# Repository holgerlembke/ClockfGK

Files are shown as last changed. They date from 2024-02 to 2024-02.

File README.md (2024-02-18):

# Clock for Generation Klick

A basic clock framework for the ESP8266 to build a WiFi syncronized clock.

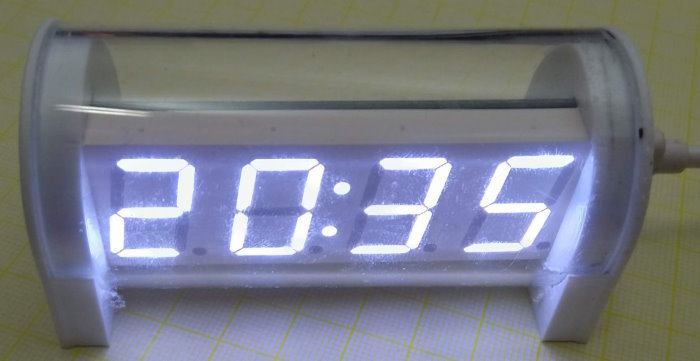
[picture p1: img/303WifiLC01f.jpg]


# History

## Hardware

It started with a simple request: could you please design a clock concept for a clock that is good readable for visually impaired humans. It should be easy to build, low cost, technological not challenging, educational, offer a path for some more DIY. Something like an eierlegende Wollmilchsau.

My 'research' resulted in that there are not so many options. I settled with three builds.

- a 2004 LC display
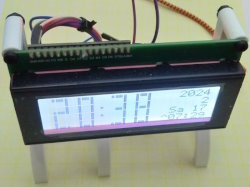
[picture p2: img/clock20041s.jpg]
    - 
    - esp8266 wemos d1 mini
    - LCD2004 display
    - i2c adapter for those displays
    - 4 x M3 x 27 screw, washer and nut
    - 2 x M3 x 20 screw, washer and nut
    - 2 x M3 x 34 screw, washer and nut
    - 30 cm x 70 cm prototype pcb
    - 2 channel bidirectional level shifter
    - some "Dupont" female header cables
    - (4.7 kOhm resistors)

- a 128x64 LC display
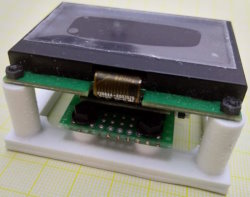
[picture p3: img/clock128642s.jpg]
    - 
    - esp8266 wemos d1 mini
    - 128 x 64 pixel i2c st7567s display
    - a 3 cm x 70 cm prototype pcb
    - 4 x M3 x 14 screw and nut
    - 4 x M2 x 12 screw and nut
    - 4-pin "Dupont" header male + female
    - (4.7 kOhm resistors)
    - (10 µF capacitor)

- a 4 x 7 segment LE display
    - Nixie Tube Wifi Clock Modul 0,8 Zoll, called 303WifiLC01
    - 79 mm long / 40 mm diameter Polymethylmethacrylat (PMMA, Acrylglas) tube
    - only for programming:
        - Programmer PCB is 2 cm x 8 cm with 6 rows x 28 holes
        - Pogo-Pins are named P75-E2 / P75-E3
        - Switches are Mini Push Button 8 mm x 8 mm Self Locking
        - UART modul is "Ch340g ch340e modul usb ttl". Look out for those that can do 3.3 V and 5 V by jumper. You need 3.3 V!
        - Clamp is a Wolfcraft FZR 3016000
        - Look at [303WifiLC01hardware.md](https://github.com/holgerlembke/ClockfGK/blob/main/clock303wifilc01/303WifiLC01hardware.md) for more details.

The last option is by far the simples, cheapest, low energy consumpting and totally unsexiest one. 

The 2004 LCD is the largest and best readable. But more difficult to build.

The 128 x 64 is for those who want an old style analog clock.

## Software

It started with a quite simple solution for the [303WifiLC01](https://github.com/holgerlembke/ClockfGK/tree/main/clock303wifilc01). Then the other hardware options came and
I decided to build a more universal clock software. So [ClockfGK](ClockfGK) came into the world.

# Software

- simple web gui for configuration
- *no* WiFi connection during runtime (other than some seconds every other hours for syncronization)
- all the time zone stuff and daylight saving
- sunrise/sundown support

It is a good starting point for designing your own clock.

## Config

At power up it always boots into Access Point mode and waits for clients. It can be configured
at http://192.168.1.1 via browser.

If no client connects it will reboot into Station mode, syncronize the clock and disconnect from WiFi.

# 3D Prints

There are some [OpenSCAD scripts](https://github.com/holgerlembke/ClockfGK/tree/main/3d%20prints) for every build.

# Stuff I used

* for the hardware schematic: https://github.com/maarten-pennings/303WIFILC01
* for the TM1650 code: https://github.com/arkhipenko/TM1650
* for the ST7567S display: https://github.com/holgerlembke/st7567sfGK
* for the LCD2004/1602: https://github.com/fdebrabander/Arduino-LiquidCrystal-I2C-library
* for the solar calculator: https://github.com/jpb10/SolarCalculator 
* Arduino core for ESP8266 WiFi chip from https://github.com/esp8266/Arduino
* Infinidash certification NDA toolkit

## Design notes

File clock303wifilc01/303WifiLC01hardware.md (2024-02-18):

# Programmer Wiring

Configure UART to 3.3 V!

```
---------+
         !            \
    5V o !  ---------T \--------> 5 V
         !
    Tx o !  --------------------> Rx 
         !
    Rx o !  --------------------> Tx
         !            \
   Io0 o !  ---------T \--o-----> Gnd   
         !                |
   Gnd o !  --------------o
         !                | 
   Gnd o !  ---------------
         !
---------+
```
Configure UART to 3.3 V!

See https://github.com/maarten-pennings/303WIFILC01/blob/main/1-pcbnets/Schematic_303WIFILC01.png for schematic and details. It would work
without the Io0 switch (press and hold S1 button), but this is way more convinient.

# Buyers Guide

* the clock modul is confusingly named something like "Nixie Tube Wifi Clock Modul 0,8 Zoll"
* Programmer PCB is 2 cm x 8 cm with 6 rows x 28 holes
* Pogo-Pins are named P75-E2 / P75-E3
* Switches are Mini Push Button 8 mm x 8 mm Self Locking
* UART modul is "Ch340g ch340e modul usb ttl". Look out for those that can do 3.3 V and 5 V by jumper. You need 3.3 V!
* Clamp is a Wolfcraft FZR 3016000

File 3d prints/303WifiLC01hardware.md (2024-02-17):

# Programmer Wiring

Configure UART to 3.3 V!

```
---------+
         !            \
    5V o !  ---------T \--------> 5 V
         !
    Tx o !  --------------------> Rx 
         !
    Rx o !  --------------------> Tx
         !            \
   Io0 o !  ---------T \--o-----> Gnd   
         !                |
   Gnd o !  --------------o
         !                | 
   Gnd o !  ---------------
         !
---------+
```
Configure UART to 3.3 V!

See https://github.com/maarten-pennings/303WIFILC01/blob/main/1-pcbnets/Schematic_303WIFILC01.png for schematic and details. It would work
without the Io0 switch (press and hold S1 button), but this is way more convinient.

# Case

For the case needs a 79 mm long / 40 mm diameter Polymethylmethacrylat (PMMA, Acrylglas) tube and those two printed parts.

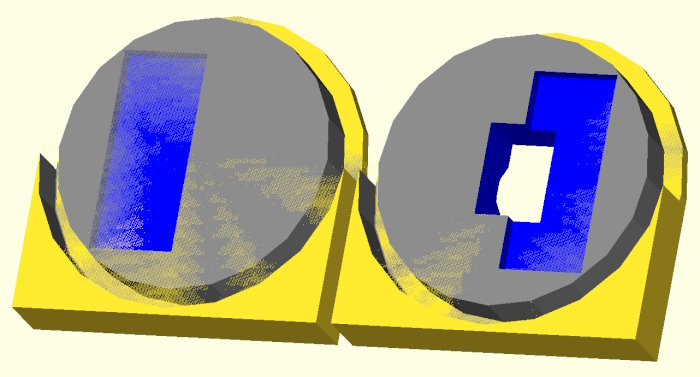
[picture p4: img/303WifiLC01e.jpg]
this is it


OpenSCAD and STL is included.

# Buyers Guide

* the clock modul is confusingly named something like "Nixie Tube Wifi Clock Modul 0,8 Zoll"
* Programmer PCB is 2 cm x 8 cm with 6 rows of 28 holes
* Pogo-Pins are named P75-E2 / P75-E3
* Switches are Mini Push Button 8 mm x 8 mm Self Locking
* UART modul is "Ch340g ch340e modul usb ttl". Look out for those that can do 3.3 V and 5 V by jumper. You need 3.3 V!
* Clamp is a Wolfcraft FZR 3016000

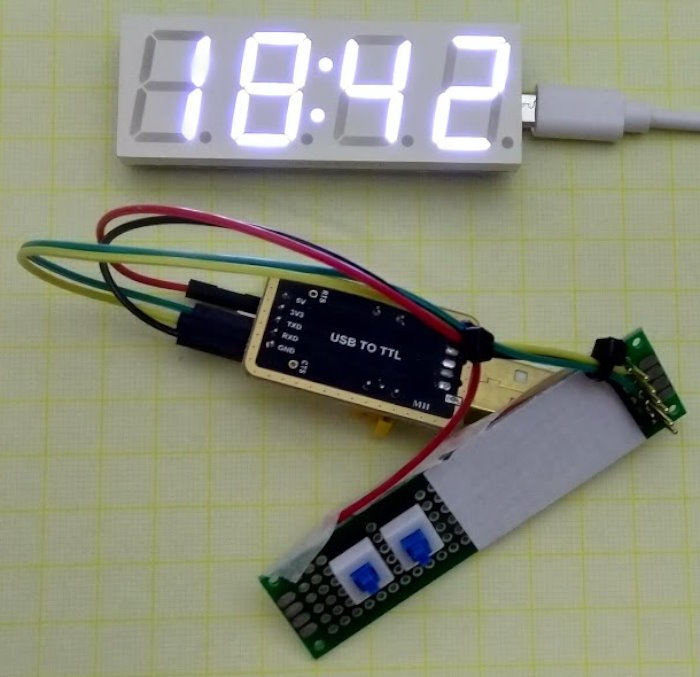
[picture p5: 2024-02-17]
img/303WifiLC01a.jpg

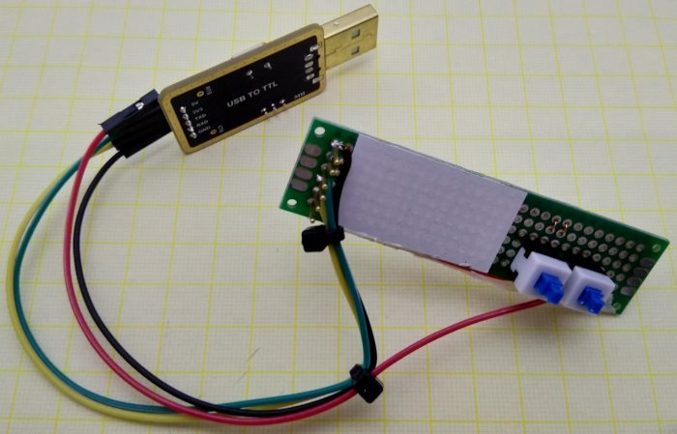
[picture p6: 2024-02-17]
img/303WifiLC01b.jpg

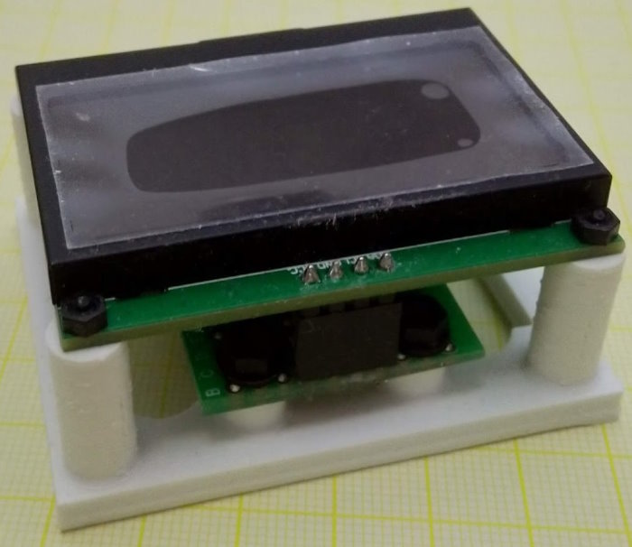
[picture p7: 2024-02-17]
img/clock128641.jpg

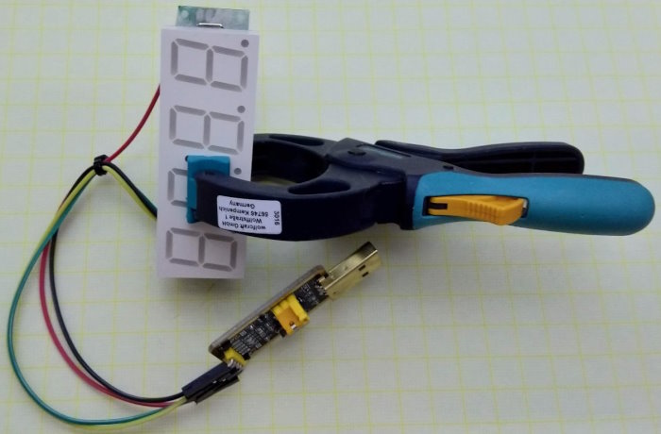
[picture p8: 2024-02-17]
img/303WifiLC01d.jpg

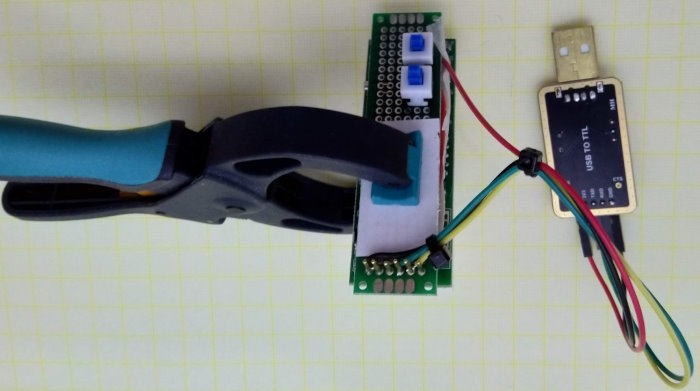
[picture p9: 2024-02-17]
img/303WifiLC01c.jpg

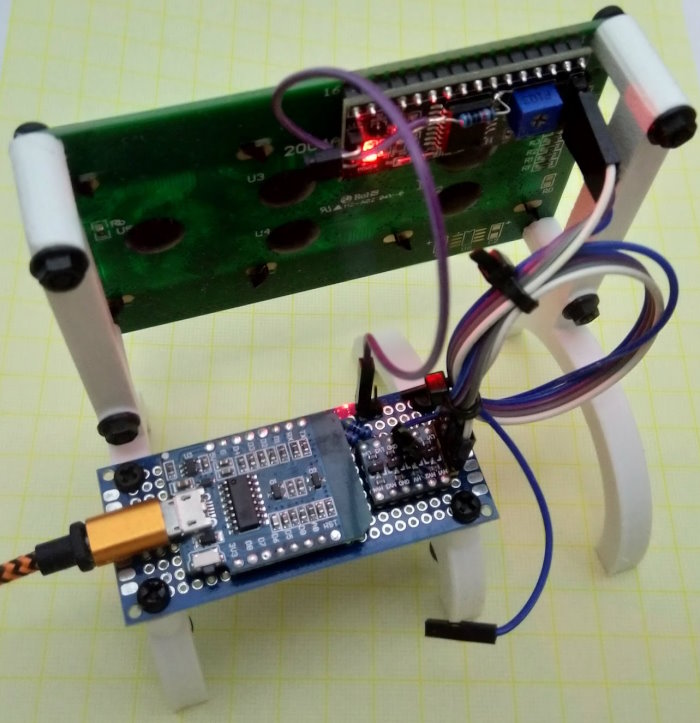
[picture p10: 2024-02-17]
img/clock20042.jpg

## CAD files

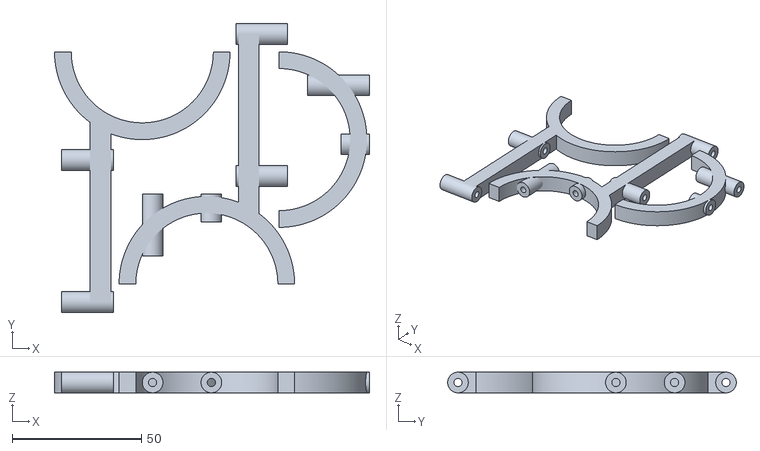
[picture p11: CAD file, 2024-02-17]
3d prints/clockLCD2004.stl
122.0 x 111.8 x 8.00

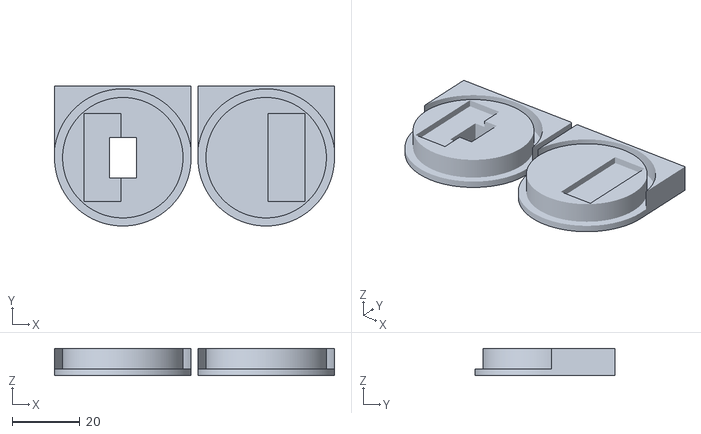
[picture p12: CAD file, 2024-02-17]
3d prints/303WifiLC01Gehäuse.stl
82.8 x 41.4 x 8.00

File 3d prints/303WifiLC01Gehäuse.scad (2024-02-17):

/*
    Gehäuseteile für
    
        303WifiLC01 Uhr 
    
    in Polymethylmethacrylat (PMMA, Acrylglas) - Röhre
         
*/

$fn = $preview ? 20 : 200;

rohrad = 40.0+0.4;
rohrid = 36.0 - 0.4;

dh1 = 2.0;
dh2 = 6.0;

lcdb = 26.0;
lcdh = 11.0;
lcdt = 2.0;
lcdofsx = 6.0;
lcdofsy = 0;

usbb = 12.0;
usbl = 8.0;
usbdm = 10.0;
usbofsx = -0;


deckela();
translate([rohrad+2,0,0]) deckelb();

//+++++++++++++++++++++++++++++++++++++++++++++++
module deckela() {
    difference() {
        enddeckel();
        union() {
            color("blue")
            translate([-lcdh/2.0-lcdofsx,-lcdb/2.0,dh2+dh1-lcdt]) cube([lcdh,lcdb,lcdt]);
            // usb-Loch
            color("blue")
            translate([0,0,0]) {
                translate([-usbl/2.0-usbofsx,-usbb/2.0,-2]) cube([usbl,usbb,20]);
                translate([-usbofsx,0,-2]) cylinder(d=usbdm,h=4);
            }
        }
    }
}

//+++++++++++++++++++++++++++++++++++++++++++++++
module deckelb() {
    difference() {
        enddeckel();
        union() {
            color("blue")
            translate([-lcdh/2.0+lcdofsx,-lcdb/2.0,dh2+dh1-lcdt]) cube([lcdh,lcdb,lcdt]);
        }
    }
}

//+++++++++++++++++++++++++++++++++++++++++++++++
module enddeckel() {
    difference() {
        union() {
            cylinder(h=dh1,d=rohrad);
            translate([0,0,dh1]) cylinder(h=dh2,d=rohrid);
            
            translate([-rohrad/2.0,0,0]) cube([rohrad,rohrad/2.0+1,dh2+dh1]);
        }
        union() {
            color("gray")
            union() {
                difference() {
                    translate([0,0,dh1]) cylinder(h=dh2,d=rohrad+0.3);
                    translate([0,0,dh1]) cylinder(h=dh2,d=rohrid);
                }
            }
        }
    }
}

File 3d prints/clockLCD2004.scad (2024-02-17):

/*
    Gehäuseteile für
    
        clockLCD2004 Uhr 
    
    Drei Anschraubteile
         
*/

$fn = $preview ? 20 : 200;

// allg. Dicke der Platte
bh = 8.0;

// Standbogen
bogenda = 68.0;
bogendi = 55.0;

// LCD
lcdlochab = 55.0;
lcdlochdmi = 3.2;
lcdlochdma = bh;
lcdlochl=bh+2.0;
lcdlochl2 = 10.0;     // Überstand auf der Seite
lcdlochofs = 17.0;
lcdtlen = 72.0;
lcdofsx = 12.2;
lcdofsy = 24.90;

pcbabs=(19.5+26.0)/2.0;
pcbha = 24.0;
pcbhb = 11.0;
pcbofsx = -21.0;
pcbofsy = 24.0;


// 0, 1, 2 für die drei Teile
zusammenbau(0);
translate([28,56,0]) rotate([0,0,-90])  zusammenbau(1);
translate([-25,90,0]) rotate([0,0,180]) zusammenbau(2);

//------------------------------------------------------------------------------------
module zusammenbau(part) {
    difference() {
        union() {
            bogen();
            if (part!=1) {
                lcdhalter();
            }
            if (part!=2) {
                pcbhalter();
            }
        }
        if (part!=2) {
            union() {
                translate([pcbofsx,pcbofsy,0]) {
                    translate([0,-50,0]) rotate([-90,-50,0]) cylinder(h=150,d=lcdlochdmi);
                    translate([pcbabs,-50,0]) rotate([-90,0,0]) cylinder(h=150,d=lcdlochdmi);
                }
            }
        }
    }
}

//------------------------------------------------------------------------------------
module pcbhalter() {
    translate([pcbofsx,pcbofsy,0])
    difference() {
        union() {
            translate([0,-(pcbha-pcbhb),0]) rotate([-90,0,0]) cylinder(h=pcbha,d=bh);
            translate([pcbabs,0,0]) rotate([-90,0,0]) cylinder(h=pcbhb,d=bh);
        }
        union() {
            rotate([-90,0,0]) cylinder(h=pcbha,d=lcdlochdmi);
            translate([pcbabs,0,0]) rotate([-90,0,0]) cylinder(h=pcbhb,d=lcdlochdmi);
        }
    }
}

//------------------------------------------------------------------------------------
module lcdhalter() {
    translate([lcdofsx,lcdofsy,-bh/2])
    difference() {
        union() {
            cube([bh,lcdtlen,bh]);
            translate([-(lcdlochl-bh)/2,lcdlochofs,bh/2]) rotate([0,90,0]) cylinder(h=lcdlochl+lcdlochl2,d=lcdlochdma);
            translate([-(lcdlochl-bh)/2,lcdlochofs+lcdlochab,bh/2]) rotate([0,90,0]) cylinder(h=lcdlochl+lcdlochl2,d=lcdlochdma);
        }
        union() {
            translate([-(lcdlochl-bh)/2,lcdlochofs,bh/2]) rotate([0,90,0]) cylinder(h=lcdlochl+lcdlochl2,d=lcdlochdmi);
            translate([-(lcdlochl-bh)/2,lcdlochofs+lcdlochab,bh/2]) rotate([0,90,0]) cylinder(h=lcdlochl+lcdlochl2,d=lcdlochdmi);
        }
    }
}

//------------------------------------------------------------------------------------
module bogen() {
    translate([0,0,-bh/2])
    intersection() {
        difference() {
            cylinder(h=bh,d=bogenda);
            cylinder(h=bh,d=bogendi);
        }
        translate([-bogenda/2.0,0,0]) cube([bogenda,bogenda,bh]);
    }
}

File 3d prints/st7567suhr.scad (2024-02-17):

/*
    Gehäuseteile für
    
        st7567s Uhr 
    
    ein Teil
    
    Platte B ist eine 30 mm x 44 mm Prototyp-PCB aus einer 
    3 cm x 7 cm Platte geschntten. Gibts bei Aliexpress.
    
    Löcher sind aufgebohrt auf 3 mm, 8 und 15 Löcher auseinander.
    
    Am besten, dieses Ding ausdrucken und ausprobieren!
 
    Zum Verschrauben:
       -- 4 x M3 x 14 mit Mutter 
       -- 4 x M2 x 12 mit Mutter
       
    zum Verbinden
       -- 4 Pin Header male/female    
         
*/

$fn = $preview ? 20 : 200;


/*
         +=================================+
         |A                     +===========+                           A|
         |                       |  B                    B  |                               |
         |                       |                            |                               |
         |                       |                            |                               |
         |                       |                            |                               |
         |                       |                            |                               |
         |                       |                            |                               |
         |                       |                            |                               |
         |                       |                            |                               |
         |                       |                            |                               |
         |                       |                            |                               |
         |                       |                            |                               |
         |                       |                            |                               |
         |                       |  B                    B  |                               |
         |A                    +===========+                            A|
         +=================================+
*/


// Loch B
lBdmi = 3.2;
lBdma = 7.3;
lBx = (7*2.54);
lBy = (14*2.54);
lBh = 5.0;
lBofsx = 0.0;
lBofsy = -0.0;

// Loch A
lAdmi = 2.2;
lAdma = 7.5;
lAx = (53.5+48.5)/2.0;
lAy = (42.9+37.9)/2.0;
lAh =  lBh + 11 + 1.5;

// Schraube für Loch A, M2 x 10, Mutter da = 4.4
// Senkung von unten ins Säule
lAIh = lAh - 6.0;
IAIdm = 5.1;

// Platte
lPx = lAx + 10.0;
lPy = lAy + 10.0;
lPd = 5.0;
// Innenaussparung wg. Material sparen
lPxl = lPx - 10.0;
lPyl = lPy - 23.0;

// Senkung für Schraubenköpfe
dmh = 3.0;
dmsk = 6.2;
dd = 1.0;

difference() {
    union() {
        translate([lBofsx,lBofsy,0])
        for (x=[-1:2:1]) {
            for (y=[-1:2:1]) {
                translate([x*lBx/2.0,y*lBy/2.0,0]) bodenplatteFuss(lBdma,lBh,dd);
            }
        }
        for (x=[-1:2:1]) {
            for (y=[-1:2:1]) {
                translate([x*lAx/2.0,y*lAy/2.0,0]) bodenplatteFuss(lAdma,lAh,dd);
            }
        }
        translate([-lPx/2.0,-lPy/2.0,-lPd]) cube([lPx,lPy,lPd]);
    }
    union() {
        translate([lBofsx,lBofsy,0])
        for (x=[-1:2:1]) {
            for (y=[-1:2:1]) {
                translate([x*lBx/2.0,y*lBy/2.0,-20]) cylinder(h=lBh+50,d=lBdmi);
                translate([x*lBx/2.0,y*lBy/2.0,-lPd]) cylinder(h=dmh,d=dmsk);
            }
        }
        for (x=[-1:2:1]) {
            for (y=[-1:2:1]) {
                translate([x*lAx/2.0,y*lAy/2.0,-20]) cylinder(h=lAh+50,d=lAdmi);
                translate([x*lAx/2.0,y*lAy/2.0,-lPd]) cylinder(h=dmh,d=dmsk);
                translate([x*lAx/2.0,y*lAy/2.0,-lPd]) cylinder(h=lAIh+lPd,d=IAIdm);
            }
        }
        for (x=[-1:1:1]) {
            for (y=[-1:1:1]) {
                translate([x*18,y*12,-10]) cylinder(d=10,h=20);                
            }
        }

        translate([-lPxl/2.0+lBofsx,-lPyl/2.0+lBofsy,-lPd-1]) cube([lPxl,lPyl,lPd+2]);
    }
}    

module bodenplatteFuss(da, hs, dd) {
    cylinder(d=da,h=hs);
    cylinder_to_plate(r1=da/2.0,r2=da/2.0+dd,h=dd);
}

//https://reprap.org/forum/read.php?247,205920
module torus(r1, r2, h, center=false) {
    torus_pipe_r=(r2-r1)/2;
    translate([0,0,center?0:h/2])
    rotate_extrude(convexity = 10)
    translate([r2-torus_pipe_r, 0, 0])
    scale([1,1/(torus_pipe_r*2)*h,1])
    circle(r = torus_pipe_r);
}

//https://reprap.org/forum/read.php?247,205920
module cylinder_to_plate(r1,r2, h, center=false) {
    translate([0,0,center?-h/2:0])
    difference() {
        difference() {
            cylinder(h=h,r1=r2,r2=r2);
            cylinder(h=h,r1=r1,r2=r1);
        }
        torus(r1=r1, r2=r2+r2-r1,h=h*2);
    }
}

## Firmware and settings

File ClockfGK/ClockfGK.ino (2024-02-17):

/*
     Clock for Generation Click

     // ..\AppData\Local\Arduino15\packages\esp8266\hardware\esp8266\3.1.2\cores\esp8266

    ++ ESP8266 <-> Arduino-Konfiguration
       
       Ziemlich egal, Flash Size 1 MB sollte klappen, auch wenn 4 MB drauf sind.

    ++ Konfiguration

        Zuerst started der ESP8266 beim Anstecken der Stromversorgung als Accesspoint 
        mit einem Webserver. Dort wartet er für 30 Sekunden, ob sich ein Client verbindet. Wenn nicht,
        bootet er erneut in einen Modus ohne Accesspoint.

        Wenn sich ein Client verbindet bekommt der eine Webseite mit der IP 192.168.1.1, URL egal.

        Das Formular zeigt *keine* gespeicherten Daten an. Sicherheit und piepapoundso.

        Nach dem Speichern wird gebootet ind den Modus ohne Accesspoint.

    ++ display

    optionale Elemente:

    ++ uselcdledcontrol
        Kontrolliert die Helligkeit des LC-Displays.

        Standard ist das LiquidCrystal_I2C-Verfahren mit .backlight();

        Hier zusätzlich kann ein PWM auf die LCD-Leitung gelegt werden. Die notwendige Software wird über
        define uselcdledcontrol bereitgestellt.

        Hardware-setup
        
        Weg 1: ohne Eingriff 
          - Kabel geht von GPIO15 zum links oberen Pin des LED-Jumpers auf dem
            PCF8574-Board. Wenn man den anderen Pin nimmt, stirbt wohl der IO-Port,
            weil da liegen 5V...
          - Leider maximal etwas dunkeler, weil Vgpio=Vcc vom ESP8266 nur 3V3 statt 5V mit dem Jumper.

        Weg 2: mit Eingriff
          Wir bauen einen Spannungsteiler an die Basis des Transistors 8050. Weil die Basis wird via 4k7 nach Vcc des
          LCD 5V hochgezogen. Würden wir da direkt rangehen, stürbe der ESP8266 GPIO (kann bis 3V6). Also Spannungsteiler 
          auf ungefähr 3V3. Geht mit 10k (3V4) bzw. 9K (3V3).

                              oDK
                            /
          ----o      3      R7  C1
          ----o    =8050=   R7  C1
                    1  2    R7  C1

          - direkt am R7 geht oben nach rechts eine sehr kurze Leiterbahn zu einer Durchkontaktierung.
          - die Leiterbahn trennen
          - dann an den Widerstand R7 oben einen Widerstand 10k (besser: 9k) nach Ground legen.
            (Wenn man einen bedrahteten Widerstand nimmt, kann man ihn zum IC legen, Ground ist rechts oben.)
          - Kabel an R7-Widerstand anlöten
          - PRÜFEN!!! Liegt nun am Kabel eine Spannung um 3V3 an? Ja: Gut. Nein: Panik!
          - anderes Ende des Kabels geht (wie oben) an GPIO15.
*/

//< < < < < < < < < < < < < < < < < < < < < < < < < < < < < < < < < < < < < < < < < < < < < < < <
//< < < < < < < < < < < < < < < < < < < < < < < < < < < < < < < < < < < < < < < < < < < < < < < <
//< < < < < < < < < < < < < < < < < < < < < < < < < < < < < < < < < < < < < < < < < < < < < < < <
// Welchen Displaytyp?
#define LCD2004 1
#define Clock303 2
#define LCD12864 3

// LCD2004   com 4
// LCD12864  com 5
// Clock303  com 5

//#define displaymode LCD2004
#define displaymode Clock303
//#define displaymode LCD12864

#define uselcdledcontrol
#if displaymode == Clock303
#undef uselcdledcontrol
#endif
#if displaymode == LCD12864
#undef uselcdledcontrol
#endif

#include <Wire.h>
#include <ESP8266WiFi.h>
#include <ESP8266WiFiMulti.h>
#include <TZ.h>
#include <sntp.h>             // nonos-sdk
#include <SolarCalculator.h>  // https://github.com/jpb10/SolarCalculator

#include <ESP8266WebServer.h>
#include <EEPROM.h>
#include <DNSServer.h>

#if displaymode == LCD12864
#include <st7567sfGK.h>
st7567sfGK display;
#endif

#if displaymode == LCD2004
#include <LiquidCrystal_I2C.h>  // https://github.com/fdebrabander/Arduino-LiquidCrystal-I2C-library
const byte LCDI2CAddr = 0x27;   // !! different LCD adapter have different I2C Addrs!
LiquidCrystal_I2C display(LCDI2CAddr, 20, 4);
#endif

struct geolocation_t {  // Braunschweig.
  double latitude = 52.2646577;
  double longitude = 10.5236066;
} geolocation;

String timezone = "";  // das wird darein kopiert bzw. geladen und genutzt!

struct accesspointdata_t {
  IPAddress ip = IPAddress(192, 168, 1, 1);
  IPAddress gateway = IPAddress(192, 168, 1, 1);  // same as ip!
  IPAddress subnet = IPAddress(255, 255, 255, 0);
  String ssid = "ClockfGK";
  const String password = "";
} accesspoint;


#if displaymode == LCD2004
const byte PinSDA = 4;
const byte PinSCL = 5;
#endif
#if displaymode == Clock303
const byte PinSDA = 13;
const byte PinSCL = 12;
#endif
#if displaymode == LCD12864
const byte PinSDA = 4;
const byte PinSCL = 5;
#endif

const byte PinBlinkLED = 2;
const int EEPromMaxSize = 512;

//********************************************************************************************************************************
ESP8266WiFiMulti wifiMulti;

enum runmode_t { undefined,
                 runasstation,
                 runasaccesspoint };
runmode_t runmode = undefined;

//********************************************************************************************************************************
void setup() {
  delay(5000);
  Serial.begin(115200);
  while (!Serial) {
    delay(100);
  }
  delay(5000);

  Serial.print(F("\n\nClock for Generation Klick "));
  Serial.print(__DATE__);
  Serial.print(F(" "));
  Serial.print(__TIME__);
#if (displaymode == LCD2004)
  Serial.print(F(" LCD2004 Mode"));
#endif
#if (displaymode == Clock303)
  Serial.print(F(" Clock303 Mode"));
#endif
#if (displaymode == LCD12864)
  Serial.print(F(" st7567s 128x64 Mode"));
#endif
  Serial.println();

  // Serial.setDebugOutput(true);

  pinMode(PinBlinkLED, OUTPUT);
  digitalWrite(PinBlinkLED, HIGH);

  // i2c Bus bzw. die Geräte in einen definierten Zustand versetzen
  I2C_ClearBus(PinSDA, PinSCL);

  // i2c
  Wire.begin(PinSDA, PinSCL, 400000);
  // Aufruf des Displayverteilers
  setupDisplay();

  timezone = String(FPSTR(TZ_Europe_Berlin));

  EEPROM.begin(EEPromMaxSize);
  LadeKonfiguationAusEEPROM();

  // install a callback that is called when sntp sets the clock via a ntp call to pool.ntp.org
  settimeofday_cb(time_is_set);
  // alles, um das mit der uhrzeit zu tun
  configTime(timezone.c_str(), "pool.ntp.org");

  //ESP8266WiFiMulti int count() { return _APlist.size(); }

  Serial.print("known Accesspoints: ");
  Serial.print(wifiMulti.count());
  Serial.println();

  // hier die Startup-Logik
  startuplogik();
}

//********************************************************************************************************************************
void startuplogik() {  // teil 1, anderer teil ist in loopAsAccesspoint()
  enum rst_reason {
    REASON_DEFAULT_RST = 0,      /* normal startup by power on */
    REASON_WDT_RST = 1,          /* hardware watch dog reset */
    REASON_EXCEPTION_RST = 2,    /* exception reset, GPIO status won’t change */
    REASON_SOFT_WDT_RST = 3,     /* software watch dog reset, GPIO status won’t change */
    REASON_SOFT_RESTART = 4,     /* software restart ,system_restart , GPIO status won’t change */
    REASON_DEEP_SLEEP_AWAKE = 5, /* wake up from deep-sleep */
    REASON_EXT_SYS_RST = 6       /* external system reset */
  };

  const rst_info *resetInfo = ESP.getResetInfoPtr();  // Resetgrund einlesen
  /*
      Nach flash: 6
      nach ESP.restart(): 4

  */
  /**/
  Serial.print("Resetreason: ");
  Serial.print(resetInfo->reason);
  Serial.println();
  /**/

  byte startmode = 0;
  ESP.rtcUserMemoryRead(0, (uint32_t *)&startmode, sizeof(startmode));

  // wir haben keinen Accesspoint in der Konfiguration, also sinnlos zu versuchen als Station zu starten
  if (wifiMulti.count() == 0) {
    Serial.println("No acccespoints in config. Can not start as station. Force AP-Mode.");
    startmode = 12;
  }

  Serial.print("Startmode: ");
  Serial.println(startmode);
  delay(500);
  displaystartupmode(startmode);

  /*
     startmode 
        1   Station
        x   Acccesspoint
  */


  if (startmode != 1) {
    runmode = runasaccesspoint;
    setupwifiAccesspoint();
    displayIP(startmode);
  } else {
    displayapwaitmessage(-3);
    runmode = runasstation;
    setupwifiStation();
    // hier gibt es noch keine IP
    // displayIP(startmode);

    /**/
    // für den nächsten Reset vorbereiten, irgendwas ungleich 1
    startmode = 32;
    ESP.rtcUserMemoryWrite(0, (uint32_t *)&startmode, sizeof(startmode));
    /**/
  }
}

//********************************************************************************************************************************
bool gotsntptime = false;
void time_is_set(bool from_sntp) {
  if (from_sntp) {
    /** /  // for debug 
    gotsntptime = true;
    /**/
    Serial.println("Timeset from sntp");
  } else {
    Serial.println("Timeset from elsewhere");
  }
}

//********************************************************************************************************************************
bool usewifi = false;
void WiFiManagement(bool turnon) {
  static WiFiMode current = (WiFiMode)15;  // because there is no undef value...

  if ((turnon) && (current != WIFI_STA)) {
    WiFi.mode(WIFI_STA);
    current = WIFI_STA;
    Serial.println("Wifi: on");
  } else {
    if ((!turnon) && (current != WIFI_OFF)) {
      WiFi.mode(WIFI_OFF);
      current = WIFI_OFF;
      Serial.println("Wifi: off");
    }
  }

  usewifi = turnon;
}

//********************************************************************************************************************************
void ZeitManagement() {
  // für den Ticker...
  static uint32_t clockticker = 0;
  const uint32_t clocktime = 15000;

  // Taskmgr.
  if (millis() - clockticker < clocktime) {
    return;
  }
  clockticker = millis();

  static byte stunde = 255;
  static byte minute = 0;
  static bool wifiswitch = false;
  const byte hourmodul = 3;
  const byte hourdelta = 0;  // wifi-check is at 0, hourmodul, hourmodul*2, ... + hourdelta
  static int hourcheck = -1;

  time_t now = time(nullptr);
  tm *lt = localtime(&now);

  // Zeit-Daten via Netz erhalten?
  if (lt->tm_year < 100) {
    WiFiManagement(true);
    //displayError();
    return;
  } else {
    // ja
    stunde = lt->tm_hour;
    minute = lt->tm_min;

    //State-Engines sind die Lösung aller Probleme
    enum wifistate_t { fetch,
                       wait4sntptime1,
                       wait4nextsync };
    static wifistate_t wifistate = fetch;

    /** /
    Serial.print("gotsntptime: ");
    Serial.print(gotsntptime);
    Serial.print(" wifistate: ");
    Serial.print(wifistate);
    Serial.println();
    /**/

    switch (wifistate) {
      case fetch:
        {
          WiFiManagement(true);
          wifistate = wait4sntptime1;
          break;
        }
      case wait4sntptime1:
        {
          if (gotsntptime) {
            WiFiManagement(false);
            hourcheck = stunde;
            wifistate = wait4nextsync;
            gotsntptime = false;
          }
          break;
        }
      case wait4nextsync:
        {
          if ((stunde % hourmodul == hourdelta) && (hourcheck != stunde)) {
            wifistate = fetch;
          }
          break;
        }
    }
  }

  // Aufruf des Zeitanzeigeverteilers
  displayTime(now);
}

//********************************************************************************************************************************
void FlashLed() {
  static uint32_t ledticker = 0;
  const int flashon = 50;
  const uint32_t flashtime = 1000l * 10l;
  static int flash = flashon;

  if (millis() - ledticker > flash) {
    ledticker = millis();
    if (!digitalRead(PinBlinkLED)) {
      flash = flashtime - flashon;
    } else {
      flash = flashon;
    }
    digitalWrite(PinBlinkLED, !digitalRead(PinBlinkLED));
  }
}

//********************************************************************************************************************************
void WifiMonitor() {
  // Wifi-Verbindung
  static uint32_t wifiticker = 0;
  const uint32_t connectTimeoutMs = 5000;

  //--------------------------
  if (millis() - wifiticker > 1000) {
    wifiticker = millis();
    if (usewifi) {
      if (WiFi.status() != WL_CONNECTED) {
        if (wifiMulti.run(connectTimeoutMs) == WL_CONNECTED) {
          Serial.print("WiFi connected: ");
          Serial.print(WiFi.SSID());
          Serial.print(" ");
          Serial.println(WiFi.localIP());
        } else {
          Serial.println("WiFi not connected!");
        }
      }
    }
  }
}

//********************************************************************************************************************************
void loop() {
  if (runmode == runasstation) {
    loopAsStation();
  }
  if (runmode == runasaccesspoint) {
    loopAsAccesspoint();
  }
  // fancy, fancy, bling bling
  FlashLed();
  // Lets wait some time...
  delay(1);
}

//

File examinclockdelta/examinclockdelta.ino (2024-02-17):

/*

    examin clock delta

    esp8266: ca. 5 sekunden/tag


*/

#include <Wire.h>
#include <privatedata.h>  // my credetial data, https://github.com/holgerlembke/privatedata
#include <TZ.h>
#include <sntp.h>  // nonos-sdk
#include <ESP8266WiFi.h>
#include <ESP8266WiFiMulti.h>
#include <WiFiUdp.h>
#include <NTPClient.h>

const byte PinSDA = 13;
const byte PinSCL = 12;

WiFiUDP ntpUDP;
NTPClient timeClient(ntpUDP);


ESP8266WiFiMulti wifiMulti;

//********************************************************************************************************************************
bool gotsntptime = false;
void time_is_set(bool from_sntp) {
  if (from_sntp) {
    gotsntptime = true;
    sntp_stop();
    Serial.println("Timeset from sntp, sntp now stopped.");
  } else {
    Serial.println("Timeset from elsewhere");
  }
}

//********************************************************************************************************************************
void setup() {
  delay(5000);
  Serial.begin(115200);
  while (!Serial) {
    delay(100);
  }
  delay(5000);
  Serial.println(F("\n\n"));

  Serial.print(F("\n\nexamin clock delta "));
  Serial.print(__DATE__);
  Serial.print(F(" "));
  Serial.print(__TIME__);
  Serial.println();

  settimeofday_cb(time_is_set);
  configTime(TZ_Etc_GMT, "pool.ntp.org");

  Wire.begin(PinSDA, PinSCL);
  displayinit();

  wifiMulti.addAP(privatedata_mySSID, privatedata_myWAP2);
  timeClient.begin();
}

//********************************************************************************************************************************
void WifiMonitor() {
  // Wifi-Verbindung
  static uint32_t wifiticker = 0;
  const uint32_t connectTimeoutMs = 5000;

  //--------------------------
  if (millis() - wifiticker > 1000) {
    wifiticker = millis();
    if (WiFi.status() != WL_CONNECTED) {
      if (wifiMulti.run(connectTimeoutMs) == WL_CONNECTED) {
        Serial.print("WiFi connected: ");
        Serial.print(WiFi.SSID());
        Serial.print(" ");
        Serial.println(WiFi.localIP());
      } else {
        Serial.println("WiFi not connected!");
      }
    }
  }
}

//********************************************************************************************************************************
void loop() {
  WifiMonitor();
  timeClient.update();


  static uint32_t ticker = 0;
  if (millis() - ticker > 1000) {
    time_t now = time(nullptr);

    if (timeClient.isTimeSet()) {
      int delta = timeClient.getEpochTime() - now;
      static int lastdelta = -12;
      if (lastdelta != delta) {
        lastdelta = delta;
        Serial.print(timeClient.getFormattedTime());
        Serial.print(" ");
        Serial.print(delta);
        Serial.println();

        displaystring(String(abs(delta)));
      }
    }
    ticker = millis();
  }
}
